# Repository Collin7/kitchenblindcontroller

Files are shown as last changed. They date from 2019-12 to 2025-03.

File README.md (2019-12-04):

# Kitchen Blind Controller

This sketch controlls a 12v DC motor, Two (2) Momentary buttons and two (2) Limit switches.

### Features of this firmware:

- MQTT Protocol
- Push button to open or close blinds
- Remotely open or close blinds via MQTT topics
- Limit switches to report on the state of the blind as well as to stop the motor when the desired state has been reached. (OPEN/CLOSED).

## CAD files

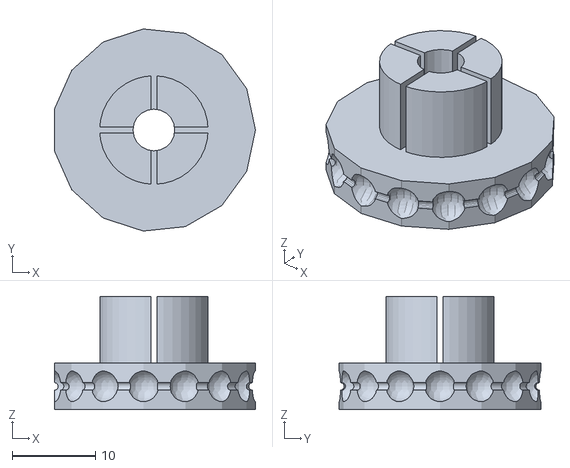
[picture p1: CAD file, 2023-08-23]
3D_Printsed_Parts/Parametric_ball_chain_pulley/Parametric_ball_chain_pulley/parametric_ball_pulley_clamp.stl
24.1 x 24.2 x 13.6

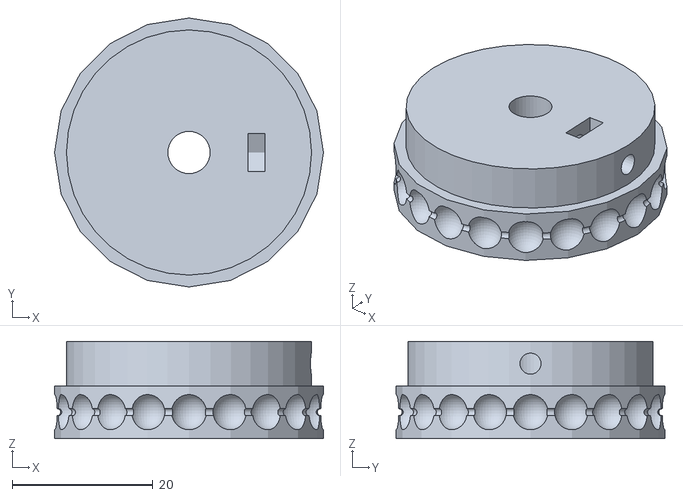
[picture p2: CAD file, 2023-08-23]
3D_Printsed_Parts/parametric_ball_pulley.stl
38.2 x 38.2 x 13.8

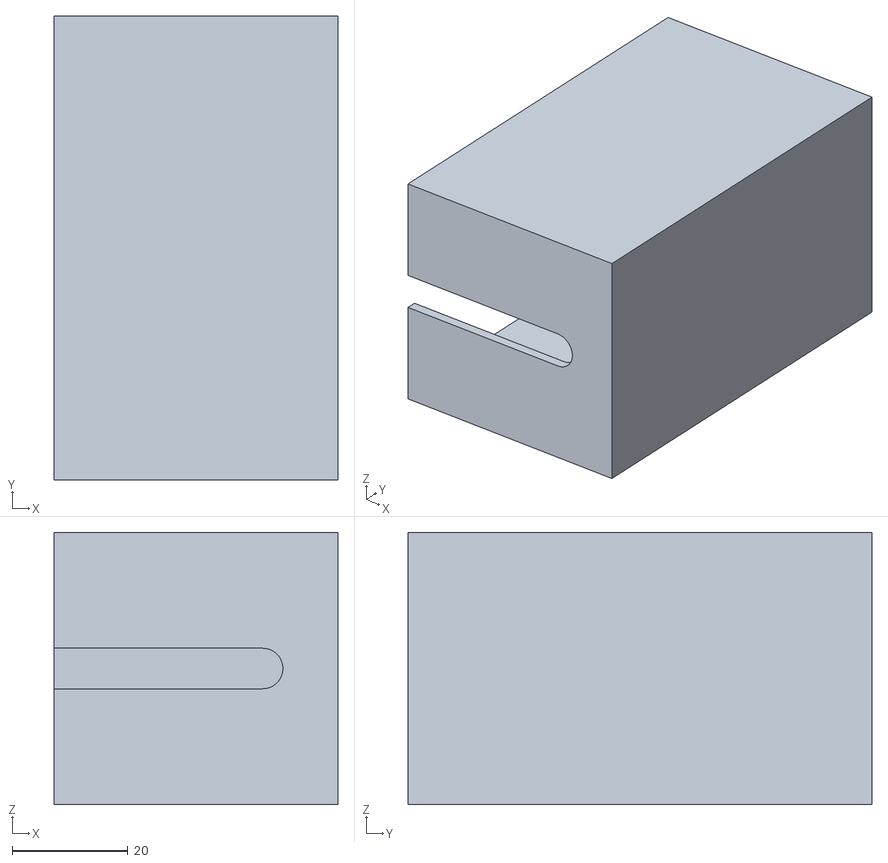
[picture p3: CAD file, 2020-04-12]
3D_Printsed_Parts/BlindMotorBox v1.stl
49.0 x 80.0 x 47.0

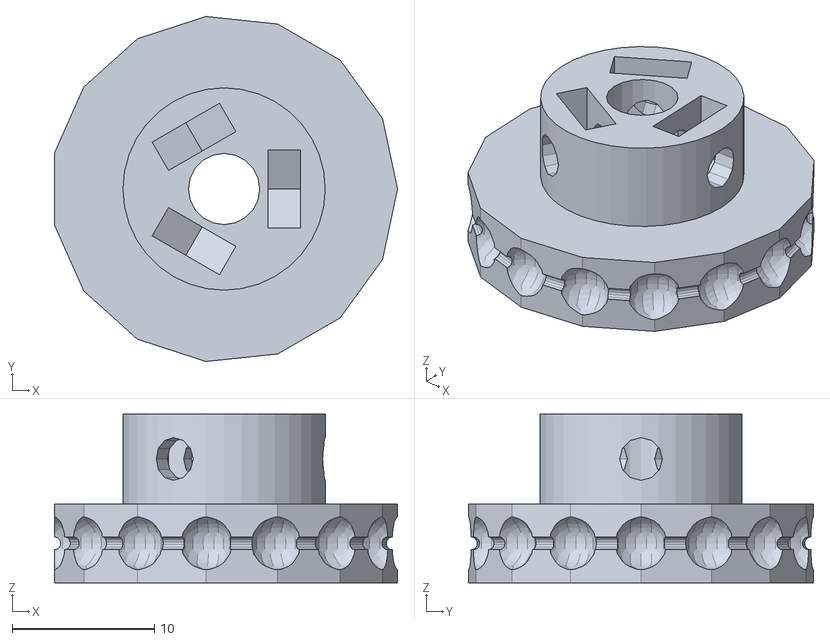
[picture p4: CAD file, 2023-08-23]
3D_Printsed_Parts/Parametric_ball_chain_pulley/Parametric_ball_chain_pulley/parametric_ball_pulley_grub.stl
24.1 x 24.2 x 11.8

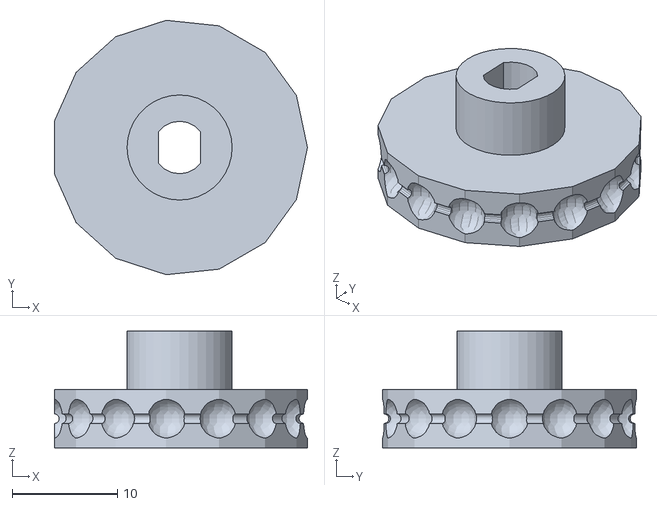
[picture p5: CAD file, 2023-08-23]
3D_Printsed_Parts/Parametric_ball_chain_pulley/Parametric_ball_chain_pulley/parametric_ball_pulley_flat.stl
24.1 x 24.2 x 11.1

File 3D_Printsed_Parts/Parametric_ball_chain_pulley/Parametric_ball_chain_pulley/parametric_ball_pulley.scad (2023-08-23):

// Parametric ball chain pulley
// Based on "Parametric Ball Pulley" by zignig (http://www.thingiverse.com/thing:1322)

// Quality of cylinders/spheres
$fa = 10;
$fs = 0.4;

// 0 = use grub screws and captive nut
// 1 = use a hose clamp
// 2 = use two "flat spots" on the shaft
// 3 = use one "flat spot" on the shaft
fastening_method = 0;

// General options
shaft_diameter = 6;
ball_diameter = 5;
ball_count = 20;
ball_spacing = 6; // The distance from the centre of one ball to the next
link_diameter = 1;

// Screw options
screw_diameter = 3;
screw_count = 1;
nut_diameter = 6.3; // correct?
nut_height = 2.4; // correct?

// Hose clamp options
clamp_inner_diameter = 13;
clamp_width = 8;

// Flat spot options
flat_spot_diameter = 4;

// Calculate dimensions
PI = 3.1415927;
wheel_diameter = ball_count*ball_spacing / PI;
wheel_height = ball_diameter*1.5;
boss_diameter = ( fastening_method == 0 ? shaft_diameter + (nut_height*2)*6 : ( fastening_method == 1 ? clamp_inner_diameter : shaft_diameter*2 ) );
boss_height = ( fastening_method == 0 ? nut_diameter : ( fastening_method == 1 ? clamp_width : wheel_height ) );
pulley_height = wheel_height + boss_height;

module pulley () {
	difference()
	{
		cylinder (pulley_height, r = wheel_diameter/2, center=true, $fn = ball_count);
		
		// Boss cutout
		translate ([0, 0, pulley_height/2])
		difference () {
			cylinder (boss_height * 2, r = wheel_diameter, center=true);
			cylinder (boss_height * 4, r = boss_diameter/2, center=true);
		}
		
		// Balls
		translate ([0, 0, pulley_height/-2 + wheel_height/2])
		for (i = [1:ball_count])
		{	
			rotate ([0, 0, (360/ball_count) * i])		
			translate ([wheel_diameter/2,0,0])
			sphere (r = ball_diameter/2);
		}
		
		// Flat spot shaft
		if (fastening_method == 2 || fastening_method == 3) {
			intersection () {
				cylinder ( pulley_height*2, r = shaft_diameter/2, center = true);
				
				translate ([ (fastening_method == 3 ? shaft_diameter/2 - flat_spot_diameter/2 : 0) , 0, 0])
				cube ([flat_spot_diameter, shaft_diameter*2,  pulley_height*3], center = true);
			}
		}
		// Normal shaft
		else {
			cylinder (pulley_height*2, r = shaft_diameter/2, center=true);
		}
		
		// Holes for links between balls
		translate ([0, 0, pulley_height/-2 + wheel_height/2])
		rotate ([0, 0, -90]) // Rotate -90 to match face direction of cylinder
		rotate_extrude (convexity = 5, $fn = ball_count)
		translate ([wheel_diameter/2, 0, 0])
		circle (r = link_diameter/2, center = true);
		
		// Screw and nut holes
		if (fastening_method == 0) {
			translate ([0, 0, pulley_height/2 - boss_height/2])
			for (i = [1: screw_count]) {
				rotate ([0, 0, 360/screw_count * i]) {
					translate ([boss_diameter/2, 0, 0])
					rotate ([0 ,90 , 0])
					cylinder (boss_diameter, r = screw_diameter/2, center = true);
					
					translate ([shaft_diameter/2 + (boss_diameter/2 - shaft_diameter/2)/2 - nut_height/4, 0, 0]) {
						rotate ([0 , 90, 0])
						cylinder (nut_height, r = nut_diameter/2, center = true, $fn = 6);
						
						translate ([0, 0, boss_height / 2])
						cube ([nut_height, sin(60) * nut_diameter, boss_height], center = true);
					}
				}
			}
		}
		// Hose clamp "splines"
		else if (fastening_method == 1) {
			translate ([0, 0, pulley_height/2])
			for (i = [0:1]) {
				rotate ([0, 0, i * 90])
				cube ([0.7, boss_diameter*2 , boss_height * 2], center = true);
			}
		}
	}
}

translate ([0, 0, pulley_height/2])
pulley();

echo ( str ("Pulley height: ", pulley_height) );
echo ( str ("Pulley diameter: ", wheel_diameter ) );

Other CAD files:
3D_Printsed_Parts/BlindMotorBox v1.f3d
3D_Printsed_Parts/BlindMotorBox v1.skp

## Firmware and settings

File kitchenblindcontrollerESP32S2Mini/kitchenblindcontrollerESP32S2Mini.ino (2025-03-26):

#include <NTPClient.h>
#include <WiFiUdp.h>
#include <WiFi.h>
#include <EasyButton.h>
#include <Credentials.h>
#include <ArduinoOTA.h>
#include <PubSubClient.h>
#include <SimpleTimer.h>

const char* DEVICE_NAME = "KITCHEN BLIND CONTROLLER";

const char* operateblind_topic = "blinds/kitchen/action";
const char* restart_topic = "blinds/kitchen/restart";

//Define Pins
const int CLOSE_BUTTON = 3;
const int OPEN_BUTTON = 5;
const int TOP_LIMIT_SWITCH = 7;
const int BOTTOM_LIMIT_SWITCH = 9;
const int IN_1 = 39;
const int IN_2 = 37;
long motorStartTime = 0;

bool didPublishState = false;
bool isMotorRunning = false;

//Initialize Objects
WiFiClient espKitchenBlindController;
PubSubClient client(espKitchenBlindController);
SimpleTimer timer;
EasyButton closeButton(CLOSE_BUTTON);
EasyButton openButton(OPEN_BUTTON);
WiFiUDP ntpUDP;
NTPClient timeClient(ntpUDP, "za.pool.ntp.org", 7200, 60000);

void setup() {
  Serial.begin(115200);

  pinMode(IN_1, OUTPUT);
  pinMode(IN_2, OUTPUT);
  pinMode(TOP_LIMIT_SWITCH, INPUT_PULLUP);
  pinMode(BOTTOM_LIMIT_SWITCH, INPUT_PULLUP);

  openButton.begin();
  closeButton.begin();

  closeButton.onPressed(closeButtonPressed);
  openButton.onPressed(openButtonPressed);

  // Set initial rotation direction
  digitalWrite(IN_1, LOW);
  digitalWrite(IN_2, LOW);

  setupWiFi();
  setupMQTT();
  setupOTA();

  timeClient.begin();

  timer.setInterval(90000, stateCheckin);  //publish blind state every 1 min
}

void loop() {
  //If MQTT client can't connect to broker, then reconnect
  if (!client.connected()) {
    reconnect();
  }
  client.loop();  //the mqtt function that processes MQTT messages
  ArduinoOTA.handle();
  buttonPressHandler();
  limitSwitchHandler();
  timer.run();

  checkMotorRuntime();
}

void checkMotorRuntime() {
  if (isMotorRunning) {
    unsigned long timeNow = timeClient.getEpochTime();
    if (timeNow - motorStartTime >= 30) {
      stopBlind();
    }
  }
}

void closeButtonPressed() {
  closeBlind();
}

void openButtonPressed() {
  openBlind();
}
void buttonPressHandler() {
  openButton.read();
  closeButton.read();
}

void limitSwitchHandler() {
  //Blind is open
  if (digitalRead(TOP_LIMIT_SWITCH) == LOW) {
    Serial.println("Top LIMIT SWITCH STOPPING BLIND");
    stopBlind();
    if (digitalRead(TOP_LIMIT_SWITCH) == LOW && !didPublishState) {
      client.publish("blinds/kitchen/state", "OPEN", true);
      didPublishState = true;
    }

    //Blind is closed
  } else if (digitalRead(BOTTOM_LIMIT_SWITCH) == LOW) {
    delay(500);  // This delay is because the reed switch changes state before the blind is all the way closed
    Serial.println("Getting called for bottom limit switch low");
    stopBlind();
    if (digitalRead(BOTTOM_LIMIT_SWITCH) == LOW && !didPublishState) {
      didPublishState = true;
      client.publish("blinds/kitchen/state", "CLOSED", true);
    }
  }
}

void stateCheckin() {
  if (digitalRead(TOP_LIMIT_SWITCH) == LOW) {
    client.publish("blinds/kitchen/state", "OPEN", true);
  }
  if (digitalRead(TOP_LIMIT_SWITCH) == HIGH) {
    client.publish("blinds/kitchen/state", "CLOSED", true);
  }
}

void openBlind() {
  motorStartTime = timeClient.getEpochTime();
  isMotorRunning = true;
  if (digitalRead(BOTTOM_LIMIT_SWITCH) == HIGH) {  //Make sure blind is currently closed
    didPublishState = false;
    digitalWrite(IN_1, HIGH);
    digitalWrite(IN_2, LOW);
    delay(2000);  // This delay to to allow the blind to release the limit switch else the low state calls stopmotor before it can start moving
  }
}

void closeBlind() {
  motorStartTime = timeClient.getEpochTime();
  isMotorRunning = true;
  if (digitalRead(TOP_LIMIT_SWITCH) == HIGH) {  //Make sure blind is currently open before closing it
    didPublishState = false;
    digitalWrite(IN_1, LOW);
    digitalWrite(IN_2, HIGH);
    delay(2000);  // This delay to to allow the blind to release the limit switch else the low state calls stopmotor before it can start moving
  }
}

void stopBlind() {
  Serial.println("StopBlind method executed");
  digitalWrite(IN_1, LOW);
  digitalWrite(IN_2, LOW);
  isMotorRunning = false;
}

void callback(char* topic, byte* payload, unsigned int length) {
  //Handle mqtt messages received by this NodeMCU
  payload[length] = '\0';
  char* command = (char*)payload;

  if (strcmp(topic, operateblind_topic) == 0) {
    if (strcmp(command, "OPEN") == 0) {
      openBlind();
    } else if (strcmp(command, "CLOSE") == 0) {
      closeBlind();
    } else if (strcmp(command, "STOP") == 0) {
      client.publish("blinds/kitchen/state", "STOPPED", true);
      stopBlind();
    }
  } else if (strcmp(topic, restart_topic) == 0) {
    restartESP();
  }
}

void setupWiFi() {

  Serial.print("Connecting to ");
  Serial.println(WIFI_SSID);

  WiFi.mode(WIFI_STA);
  WiFi.begin(WIFI_SSID, WIFI_PASSWORD);

  unsigned long startTime = millis();
  while (WiFi.status() != WL_CONNECTED) {
    delay(500);
    Serial.print(".");

    // Timeout if connection takes to long (15 seconds)
    if (millis() - startTime > 15000) {
      restartESP();
    }
  }

  Serial.println("");
  Serial.println("WiFi connected");
  Serial.println("IP address: ");
  Serial.println(WiFi.localIP());
  Serial.println("MAC: ");
  Serial.println(WiFi.macAddress());
}

void setupMQTT() {
  client.setServer(MQTT_SERVER, MQTT_PORT);
  client.setCallback(callback);  // callback is the function that gets called for a topic subscription

  Serial.println("Attempting MQTT connection...");
  if (client.connect(DEVICE_NAME, MQTT_USERNAME, MQTT_PASSWORD)) {
    Serial.println("Connected to MQTT broker");
    subscribeMQTTTopics();
  } else {
    Serial.print("Failed to connect to MQTT broker. RC=");
    Serial.println(client.state());
    Serial.println("Restarting ESP...");
    restartESP();
  }
}

void subscribeMQTTTopics() {
  client.subscribe("blinds/kitchen/#");
}

void setupOTA() {
  ArduinoOTA.setHostname(DEVICE_NAME);
  ArduinoOTA.begin();
}

void reconnect() {

  // Reconnect to WiFi and MQTT
  if (WiFi.status() != WL_CONNECTED) {
    setupWiFi();
  }

  // Check if MQTT connection is not established
  if (!client.connected()) {
    setupMQTT();
  }
}

void restartESP() {
  ESP.restart();
}

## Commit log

2019-10-29 Added delay for button press to allow blind to move off limit switch and not read switch for 2 sec
2019-11-08 Preventing opening when open or closing when already closed
    [kitchenblindcontroller.ino]
2019-12-14 Changed button press to use EasyButton library to handle button pressing
2019-12-29 Added stop blind command if MQTT disconnects, incase motor is turning and mqtt drops. Code will not listen for limit switch, so we should just stop the motor
2020-04-12 Added 3d print files
    [BlindMotorBox v1.f3d, BlindMotorBox v1.skp, BlindMotorBox v1.stl]
2022-05-12 Added timer to stop motor if limit button is missed
    [kitchenblindcontroller.ino]
2022-07-11 used NTP for motor timing shutoff
2023-04-28 Added delay for closing blinds, reed switch triggers before blinds are at the bottom
2023-08-23 Added 3d files
    [parametric_ball_pulley.scad, parametric_ball_pulley.stl, parametric_ball_pulley_clamp.stl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]
2025-03-21 Update kitchenblindcontroller.ino
    fix easy button library and replaced d1 again
    [kitchenblindcontroller.ino]
2025-03-26 ESP32 Sketch
